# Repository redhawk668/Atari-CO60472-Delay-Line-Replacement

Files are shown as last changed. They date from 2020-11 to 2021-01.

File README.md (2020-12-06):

# Atari CO60472 Delay Line Replacement

# First Draft
This small PCB is a replacement for the proprietary CO60472 Delay Line chip used in the Atari XL series of computers. It is based on schematics found on the AtariAge forums (https://atariage.com/forums/topic/253024-co60472-delay-line/)

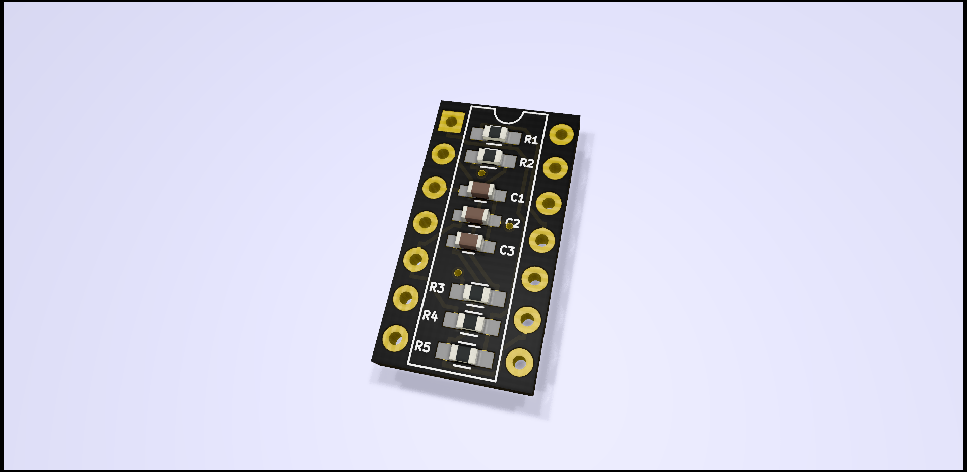
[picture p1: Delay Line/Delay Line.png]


Installed in a 600XL:

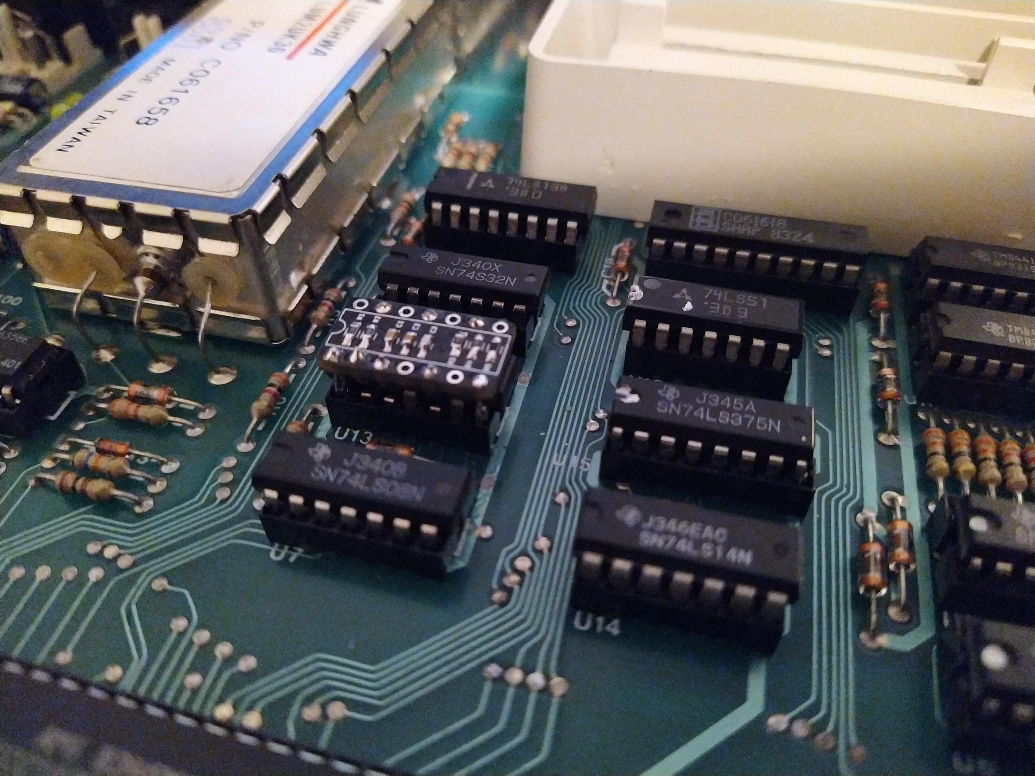
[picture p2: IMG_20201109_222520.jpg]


The little board, once assembled, is piggybacked on top of a 74LS14 Hex Inverter.

# Billing of Materials:
- 1x 74LS14 or 74HC14 Hex Inverter Schmitt Trigger

Resistors:
- R1  : 120R Resistor, 0603
- R2  : 100R Resistor, 0603
- R3  : 120R Resistor, 0603
- R4  : 270R Resistor, 0603
- R5  : 620R Resistor, 0603

Capacitors:
- C1  : 1nF X7R Capacitor, 0603
- C2  : 150pF X7R Capacitor, 0603
- C3  : 30pF X7R Capacitor, 0603

Bend up pins 2,3,5,9,11 and 13, solder the little PCB on top of the 74LS14. Connect pins 1 and 7 to the PCB. 

# Rev. A
This is a rework of the first design. The functionality is still the same, for this design it is not necessary to bend up pins on the the IC and piggybacking the PCB on top of the IC. The IC can now be soldered on top of the PCB, along with the resistors and capacitors. PCB thickness should be 0.6mm.

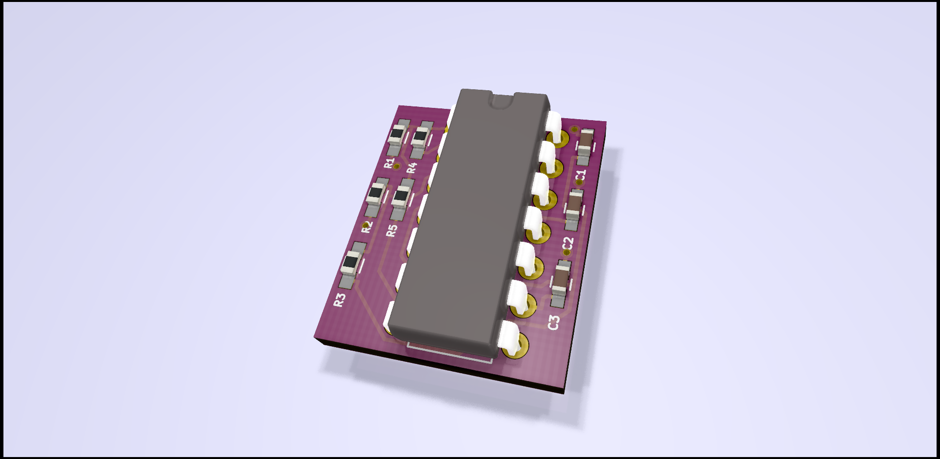
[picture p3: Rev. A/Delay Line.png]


# Billing of Materials

Billing of materials is the same as the first design.

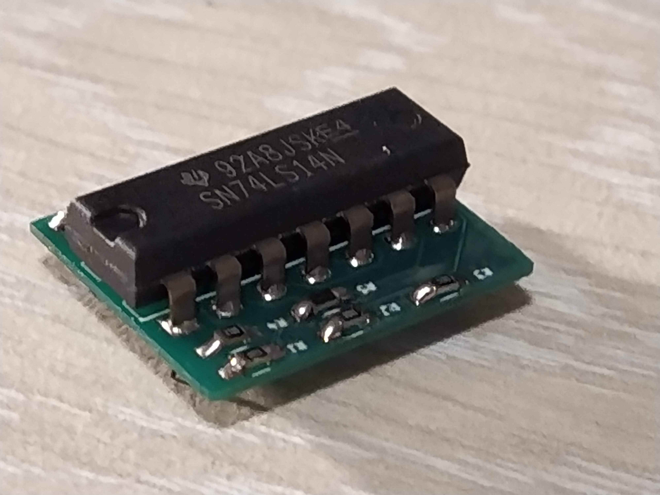
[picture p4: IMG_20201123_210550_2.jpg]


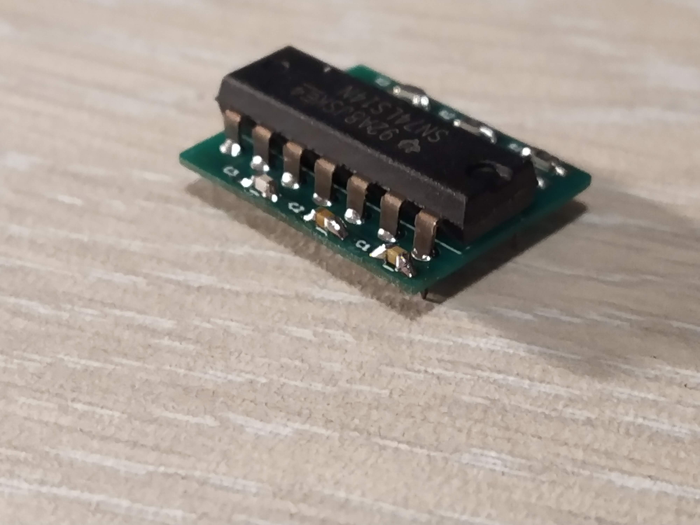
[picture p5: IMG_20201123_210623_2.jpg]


This is Rev. A installed in a 600XL, fits perfectly:

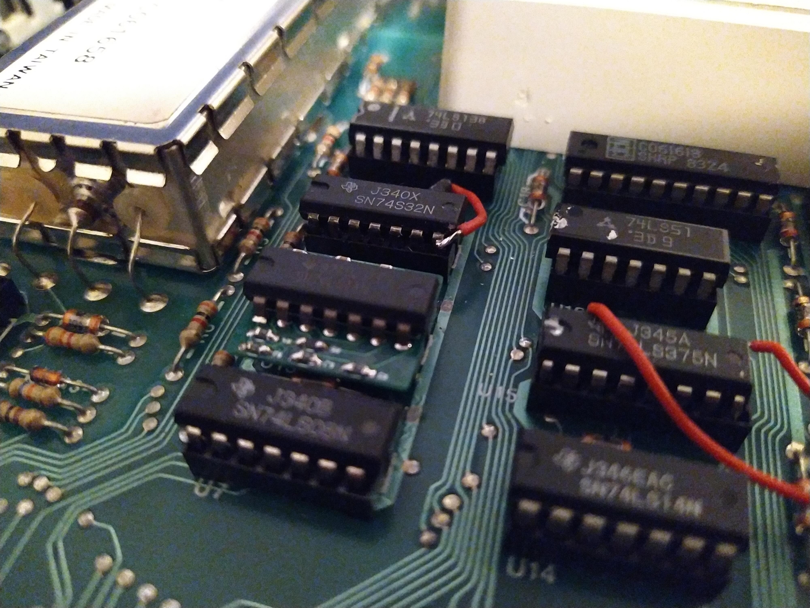
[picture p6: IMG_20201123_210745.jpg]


# Rev. B
A little rework of Rev. A. This is a full SMD design. However, due to space restrictions it has the same form factor as Rev. A. Functionality is still the same. 

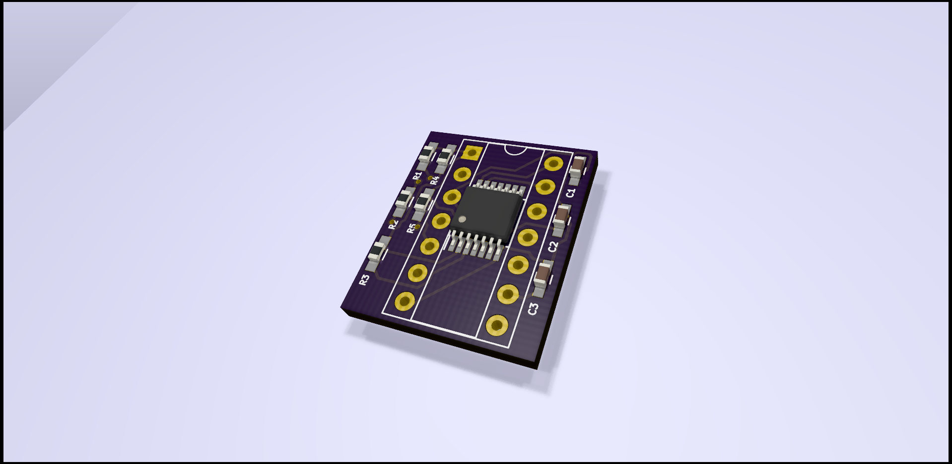
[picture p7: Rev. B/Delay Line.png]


# Billing of Materials
- 1x 74LS14 or 74HC14 TSSOP-14 SMD package

Resistors:
- R1  : 120R Resistor, 0603
- R2  : 100R Resistor, 0603
- R3  : 120R Resistor, 0603
- R4  : 270R Resistor, 0603
- R5  : 620R Resistor, 0603

Capacitors:
- C1  : 1nF Ceramic Capacitor, 0603
- C2  : 150pF Ceramic Capacitor, 0603
- C3  : 30pF Ceramic Capacitor, 0603

Machine pin headers (Omron XR2P-3241)

# Rev. C
Another rework, this is a a lot smaller. Everything now fits within the DIP-14 footprint. The Billing of Materials is the same as Rev. B. 

# Top
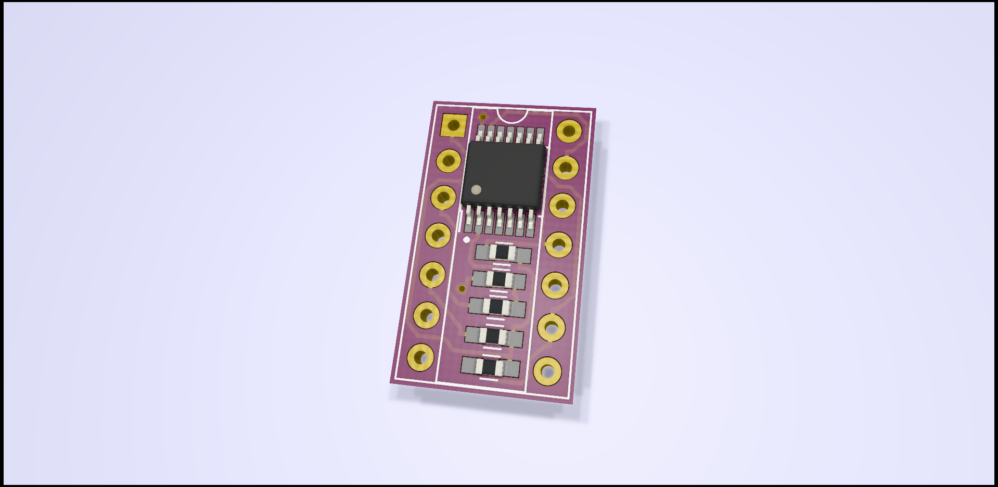
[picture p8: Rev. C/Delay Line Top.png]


# Bottom
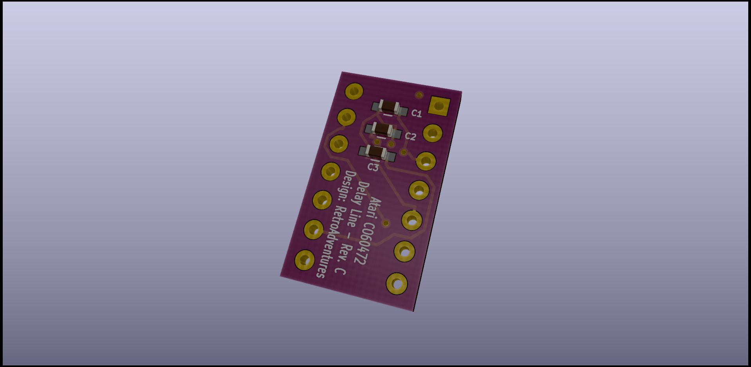
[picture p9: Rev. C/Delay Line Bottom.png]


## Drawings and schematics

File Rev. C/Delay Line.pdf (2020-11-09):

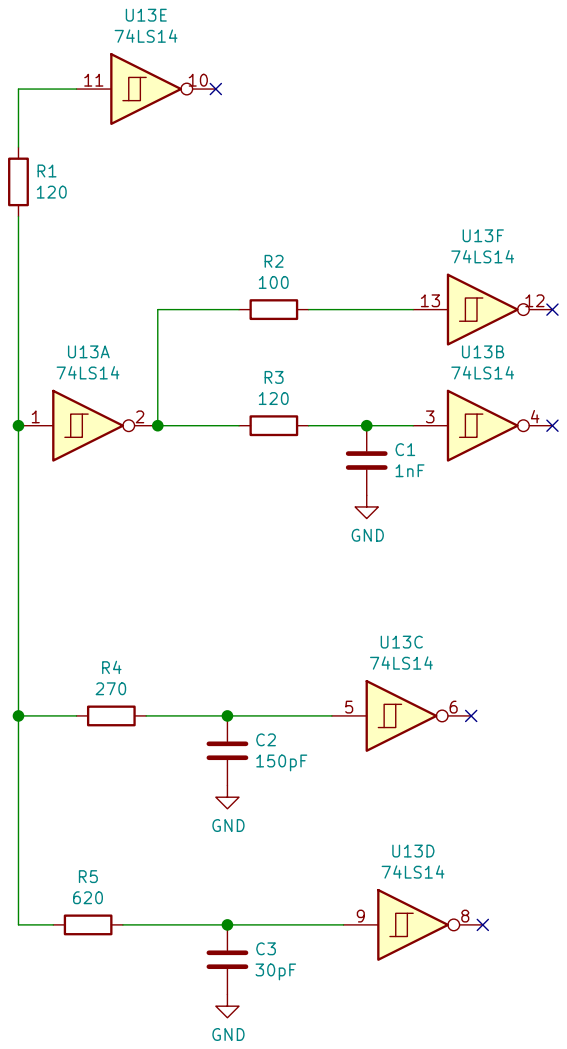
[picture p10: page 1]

File: Delay Line.sch Sheet: /
Id: 1/1 Title:

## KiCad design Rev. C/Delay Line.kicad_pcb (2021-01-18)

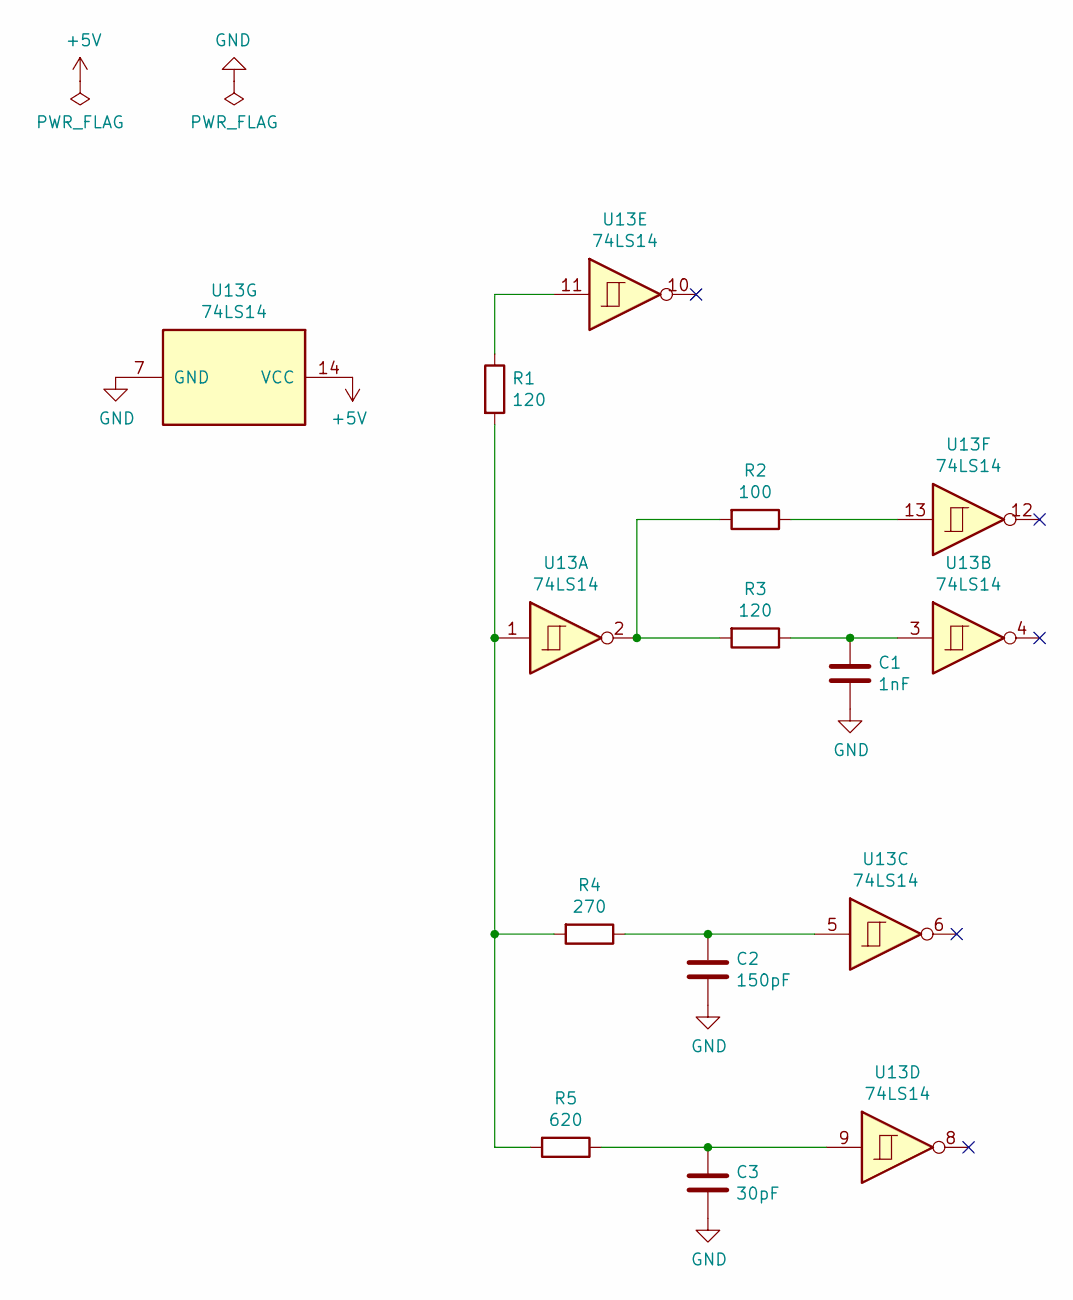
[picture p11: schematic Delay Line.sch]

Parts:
C1: 1nF; C_0603_HandSoldering
C2: 150pF; C_0603_HandSoldering
C3: 30pF; C_0603_HandSoldering
R1, R3: 120; R_0603_HandSoldering
R2: 100; R_0603_HandSoldering
R4: 270; R_0603_HandSoldering
R5: 620; R_0603_HandSoldering
U13: 74LS14; TSSOP-14_4.4x5mm_Pitch0.65mm

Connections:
+5V: U13.14 (VCC)
GND: C1.2, C2.2, C3.2, U13.7 (GND)
unnamed: C1.1, R3.1, U13.3
unnamed: C2.1, R4.1, U13.5
unnamed: C3.1, R5.1, U13.9
unnamed: R1.1, U13.11
unnamed: R1.2, R4.2, R5.2, U13.1
unnamed: R2.1, U13.13
unnamed: R2.2, R3.2, U13.2

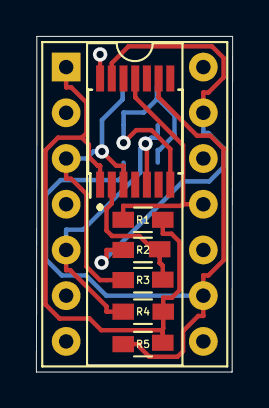
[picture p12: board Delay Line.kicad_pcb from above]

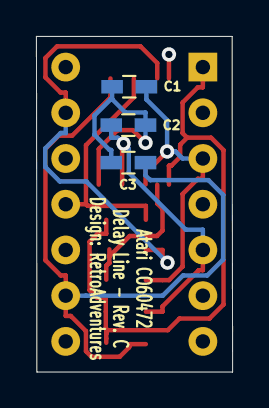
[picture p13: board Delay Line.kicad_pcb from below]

Board: 4 copper layers, 10.9 x 18.6 mm, 9 parts (3 on the bottom side), 8 nets.

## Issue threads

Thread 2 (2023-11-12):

74HC14 vs 74LS14 vs 74HCT14

mmatt80, 2023-11-12:
In the BOM, you call for a 74LS14 or 74HC14.  I built one and used a 74HC14 and was having issues with it.  I was having a hard time finding a 30pF cap, so used a 33pF instead at c3.  I'm not sure if I worked it out correctly, but I swapped R5 for a 560R resistor to hopefully get the timing back to were it should be.  This still didn't work, and knowing that HC isn't TTL compatible, I found a spare 74LS14 on a spare expansion board I had.  Put this in and the atari is now working as expected!  So I think you might have meant 74HCT14 instead of 74HC14?

Thanks for you work on this project, it helped to save another atari!

redhawk668, 2024-01-15:
Indeed, my bad. It should be a 74HCT14 or 74LS14. 74HC14 is not TTL compatible, so the timing will not be correct.

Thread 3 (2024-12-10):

Rev C does not work

rsxm5, 2024-12-10:
As a word of warning to others, the Rev C version of this project does not seem to work.  It was discussed in an Atari forum that the PCB design appears incomplete.  I ended up going with the Rev A version of this as I had leftover THT 74LS14 DIPs and those completed boards are working perfectly.
